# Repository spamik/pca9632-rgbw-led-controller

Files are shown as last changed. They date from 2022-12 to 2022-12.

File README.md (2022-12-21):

# PCA9632 RGBW LED controller

This project is a PCB design files for RGBW LED controller based on PCA9632 chip. This controller was designed for controlling RGBS LED strips on 3D printer. PCA9632 chip has support in Marlin firmware so with this PCB it's needed only connect LED strips, power supply and I2C to printer controller.

##### Main highlights:
  * Molex Micro-Fit connectors for all outside connections (power supply, I2C communication and two 5 pin outputs for LED strips)
  * 24V compatible
  * Included MOSFETs

##### Project contents:
  * **pca9632_lec_controller_pcb:** KICAD source files for PCB and schematics
  * **gerber:** gerber factory files for PCB (compatible with JLCPCB)
  * **box_3d_models:** 3D printable box for electronics

##### Picture of assembled PCB:
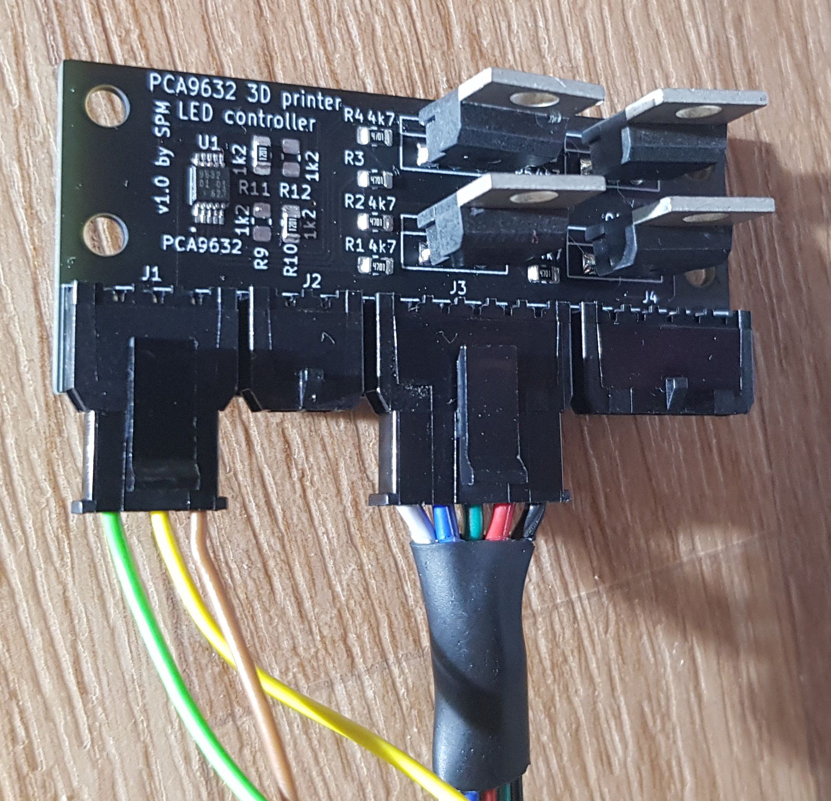
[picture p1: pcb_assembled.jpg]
Assembled PCB


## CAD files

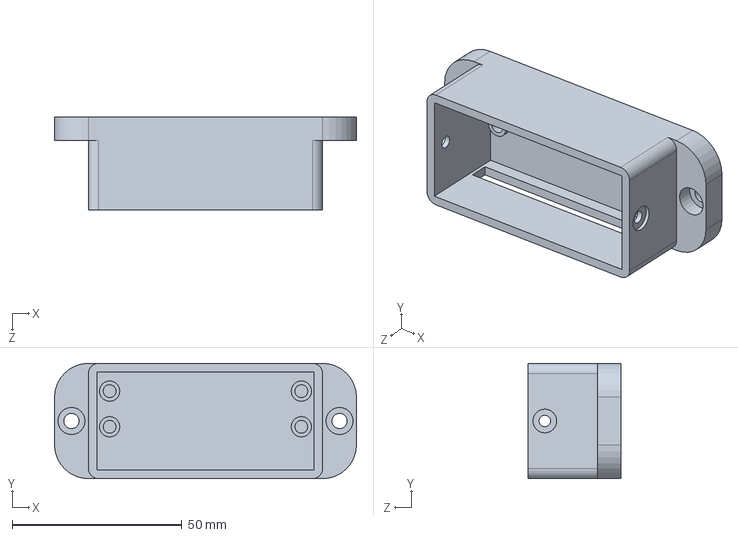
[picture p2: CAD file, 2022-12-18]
box_3d_models/pca9632_box_bottom.SLDPRT
89.0 x 34.0 x 27.5 mm

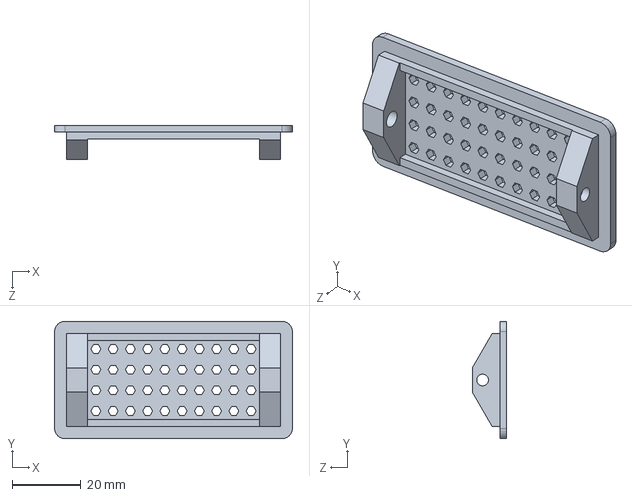
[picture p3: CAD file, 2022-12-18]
box_3d_models/pca9632_box_top.SLDPRT
69.0 x 34.0 x 10.0 mm

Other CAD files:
box_3d_models/pca9632_box_bottom.STL
box_3d_models/pca9632_box_top.STL

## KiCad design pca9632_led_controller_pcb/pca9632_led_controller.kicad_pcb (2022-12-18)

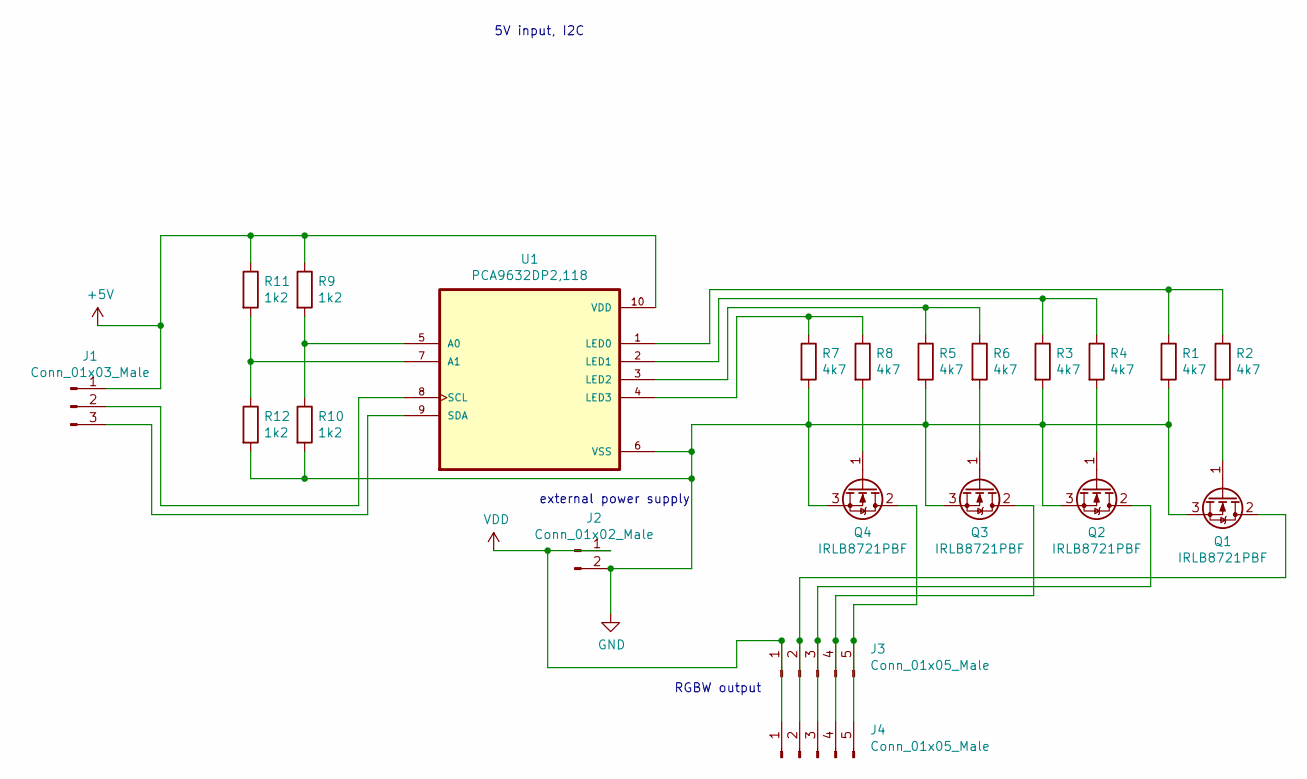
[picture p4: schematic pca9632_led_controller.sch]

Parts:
J1: Conn_01x03_Male; Molex_Micro-Fit_3.0_43650-0300_1x03_P3.00mm_Horizontal
J2: Conn_01x02_Male; Molex_Micro-Fit_3.0_43650-0200_1x02_P3.00mm_Horizontal
J3, J4: Conn_01x05_Male; Molex_Micro-Fit_3.0_43650-0500_1x05_P3.00mm_Horizontal
Q1, Q2, Q3, Q4: IRLB8721PBF; TO-220-3_Vertical
R1, R2, R3, R4, R5, R6, R7, R8: 4k7; R_0805_2012Metric_Pad1.20x1.40mm_HandSolder
R9, R10, R11, R12: 1k2; R_0805_2012Metric_Pad1.20x1.40mm_HandSolder
U1: PCA9632DP2,118; SOP50P490X110-10N; PARTREV 5

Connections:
+5V: J1.1, R9.1, R11.1, U1.10 (VDD)
GND: J2.2, Q1.3 (S), Q2.3 (S), Q3.3 (S), Q4.3 (S), R1.2, R3.2, R5.2, R7.2, R10.2, R12.2, U1.6 (VSS)
unnamed: J1.2, U1.8 (SCL)
unnamed: J1.3, U1.9 (SDA)
unnamed: J3.2, J4.2, Q1.2 (D)
unnamed: J3.3, J4.3, Q2.2 (D)
unnamed: J3.4, J4.4, Q3.2 (D)
unnamed: J3.5, J4.5, Q4.2 (D)
unnamed: Q1.1 (G), R2.2
unnamed: Q2.1 (G), R4.2
unnamed: Q3.1 (G), R6.2
unnamed: Q4.1 (G), R8.2
unnamed: R1.1, R2.1, U1.1 (LED0)
unnamed: R3.1, R4.1, U1.2 (LED1)
unnamed: R5.1, R6.1, U1.3 (LED2)
unnamed: R7.1, R8.1, U1.4 (LED3)
unnamed: R9.2, R10.1, U1.5 (A0)
unnamed: R11.2, R12.1, U1.7 (A1)
VDD: J2.1, J3.1, J4.1

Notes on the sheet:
5V input, I2C
external power supply
RGBW output

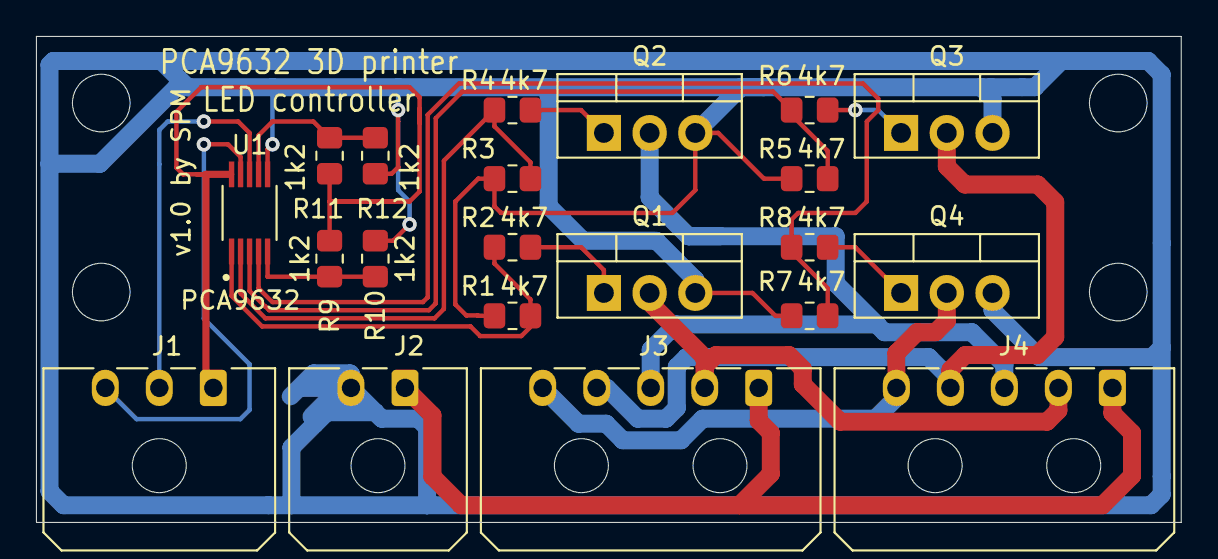
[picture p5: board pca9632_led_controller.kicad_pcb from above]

Board: 2 copper layers, 63.6 x 27.0 mm, 21 parts (0 on the bottom side), 19 nets.

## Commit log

2022-12-18 Initial import
    [pca9632_box_bottom.SLDPRT, pca9632_box_bottom.STL, pca9632_box_top.SLDPRT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]
2022-12-19 Added photo of assembled PCB
